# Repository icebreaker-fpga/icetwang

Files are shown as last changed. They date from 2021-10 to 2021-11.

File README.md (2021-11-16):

The iCEBreaker-Bitsy FPGA based 1D LED game system.

This repository contains hardware, gateware and firmware for the system.

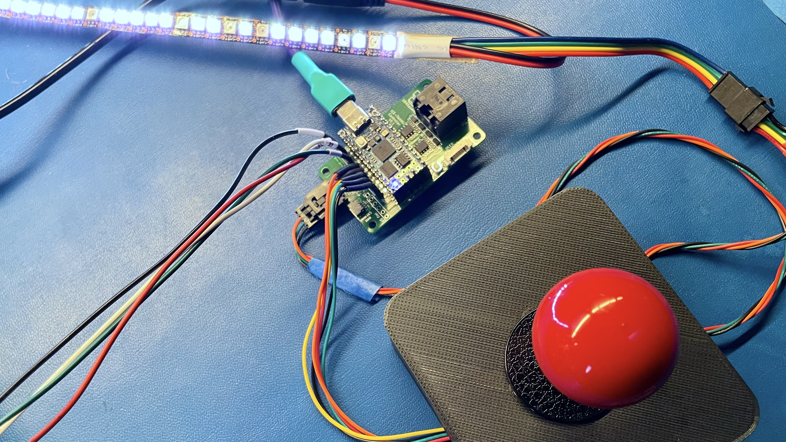
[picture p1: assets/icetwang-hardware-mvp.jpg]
The minimum vaiable setup, using the iCEtwang controller board, an APA102 LED strip and an arcade joystick

**The minimum vaiable setup, using the iCEtwang controller board, an APA102 LED strip and an arcade joystick**

# What is it

The original intention was to implement a [TWANG](https://www.buildlog.net/blog/2018/01/twang/)
inspired game, using FPGA instead of a microcontroller. In turn TWANG was inspired by the game
called [Line Wobbler](https://wobblylabs.com/projects/wobbler).

The scope of the project has expanded a bit since it's inception. The added
goals are multiplayer and remote LED strings, as well as additional games
beyond the 1D Dungeon game that the predecessor TWANG game implemented.

# Simulator

This repository also contains a simulator that allows you to play the game on
the desktop using keyboard arrow keys. It is very useful to try out the game
without the hardware, as well as debugging and development of the games.

iCEtwang simulator window
**The iCEtwang simulator window**

You can find it in the `sim` subdirectory.

## How to build the hardware

TODO: Hardware build information goes here...

## How to build the gateware

* Connect the iCEBitsy in DFU bootloader mode to your computer.
* In the `soc/ice-twang` directory run `make dfuprog`

## How to build the firmware

* Connect the iCEBitsy in DFU bootloader mode to your computer.
* In the `firmware/icetwang-controller` or `firmware/icetwang-pole` directory
  run `cargo run --release`

## More information

You should be able to find some more README.md files distributed around this
repository, describing more details of each of the system components.

If you have questions you can always join [our discord
server](https://1bitsquared.com/pages/chat) and ask questions there.

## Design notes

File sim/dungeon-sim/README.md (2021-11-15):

This is a desktop simulation of the iCEtwang-dungeon game.

This uses the game core from `../firmware/icetwang-dungeon` directory, and simulates the input using keyboard, and output using a graphical LED strip emulation.

To build the simulator just have rust installed and run:

```
cargo run
```

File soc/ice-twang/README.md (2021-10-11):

RISC-V core for 1D LED games (iCETWANG)
=========================================

For the iCEBreaker-bitsy, the hardware connections are :
  * `42`: USB DP
  * `38`: USB DN
  * `37`: Pull up. Resistor of 1.5 kOhm to USB DP 

To run :
  * Build and flash the bitstream
      * `make dfuprog`
      * This will build `fw/boot.hex` and include it as the BRAM initial data

  * You can flash the test c application code in SPI at offset 1M
      * `make -C fw dfuprog`
  
  * This project's main application can be found in `../../firmware/`
    directory. Follow the instructions there.

  * Connect to the iCEBreaker-bitsy uart console (P0, P1) with a 1M baudrate
      * and then at the `Command>` prompt, press `r` for 'run'. This will
        start the USB detection and device should enumerate

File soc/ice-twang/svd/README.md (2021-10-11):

The SVD file generator for icetwang-soc.

# How to generate the SVD file
The SVD file is generated using svdtools.

To install svdtools run:
```
pip3 innstall --upgrade --user svdtools
```

Or if you are on Arch you can install the svdtools AUR.

You can then run the `gensvd.sh` script. This will generate the svd file and
drop it into `../../../firmware/icetwang-pac`.

# How to add registers

Just edit the icetwang-soc.yaml file and add more registers.

For syntax refer to the [svdtools
documentation](https://pypi.org/project/svdtools/#device-and-peripheral-yaml-format).

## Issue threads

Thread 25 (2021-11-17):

Implement IMU driver

esden, 2021-11-17:
It depends on #24

esden, 2021-12-15:
It is now partly implemented. It can be tested in the blinky firmware. Still needs to be fully implemented in the main game firmware.

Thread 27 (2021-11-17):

Implement movable spring controller

esden, 2021-11-17:
The original spring controller has to be affixed to a solid surface. As we want to read out the bend of the spring and not the movement of the controller. We could solve the issue by adding a second IMU inside the controller itself and use its output as the reference frame to the IMU on the spring tip.

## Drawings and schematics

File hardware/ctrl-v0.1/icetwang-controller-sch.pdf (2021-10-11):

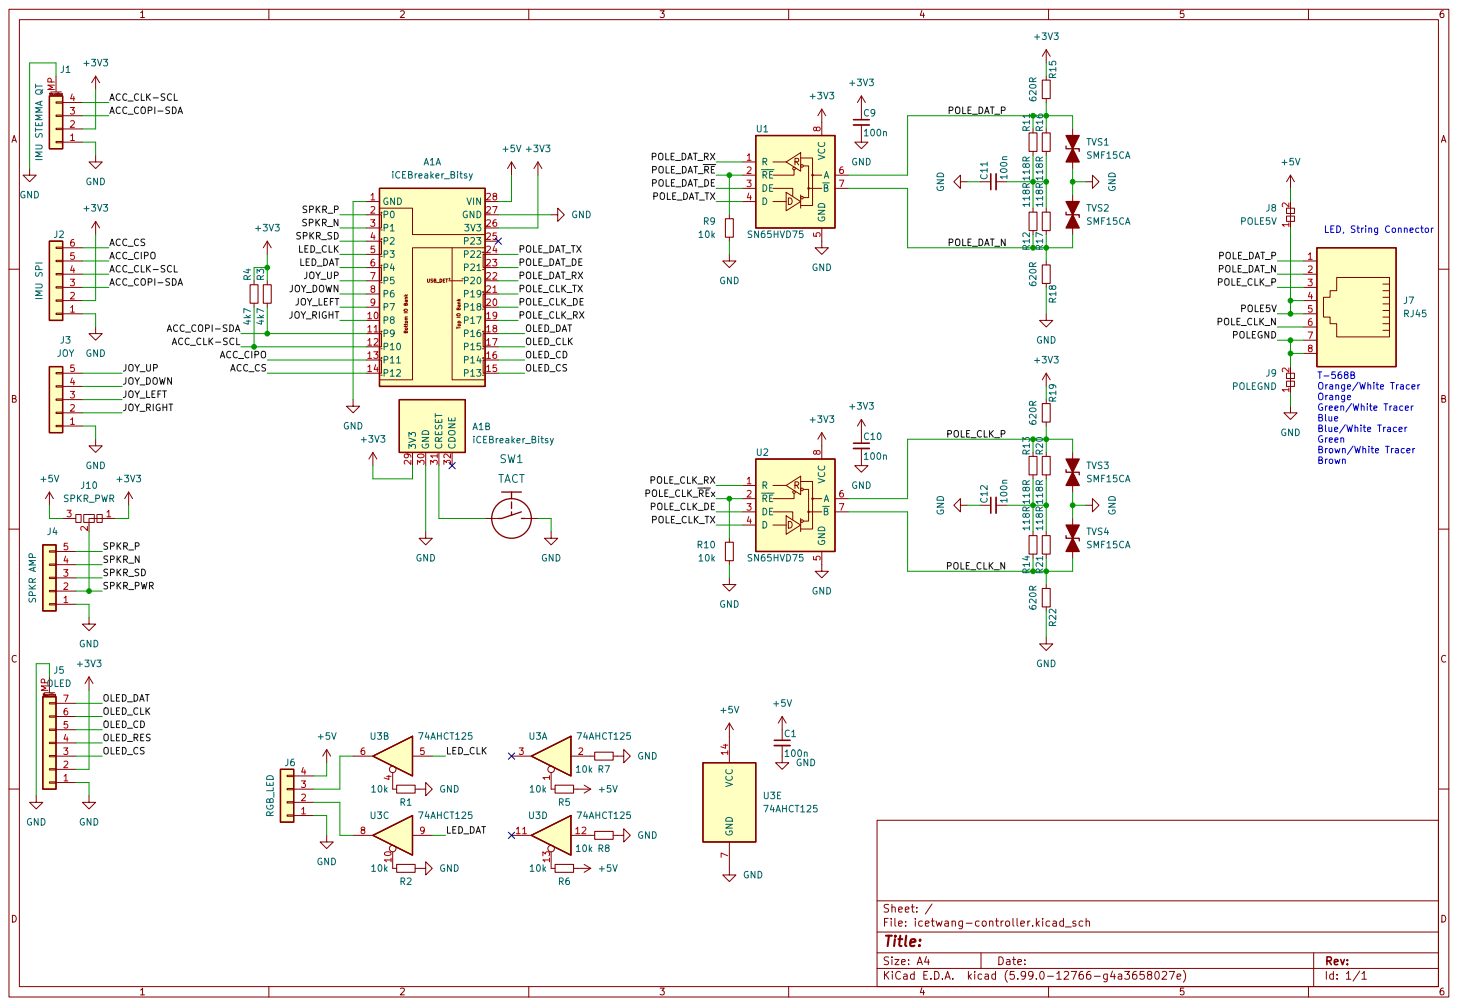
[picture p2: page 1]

LED, String Connector T-568B Orange/White Tracer

Orange Green/White Tracer Blue Blue/White Tracer Green Brown/White Tracer Brown

File: icetwang-controller.kicad_sch Sheet: / +5V
J6 RGB_LED

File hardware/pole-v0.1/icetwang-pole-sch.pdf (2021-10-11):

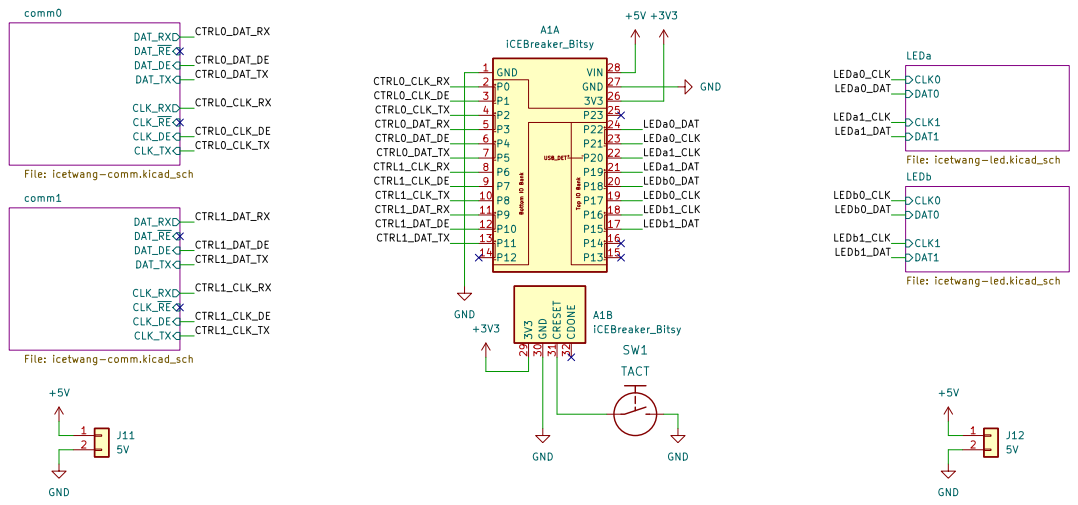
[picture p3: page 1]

LEDa File: icetwang-led.kicad_sch

License: CC-BY-SA 4.3 CLK_~{RE} CLK_RX CLK_DE CLK_TX DAT_DE DAT_~{RE} DAT_RX DAT_TX

(C) 2021 Piotr Esden-Tempski <piotr@esden.net>
(C) 2021 1BitSquared <info@1bitsquared.com>
File: icetwang-pole.kicad_sch Sheet: / 1BitSquared

Id: 1/5 Title: iCE-TWANG Pole

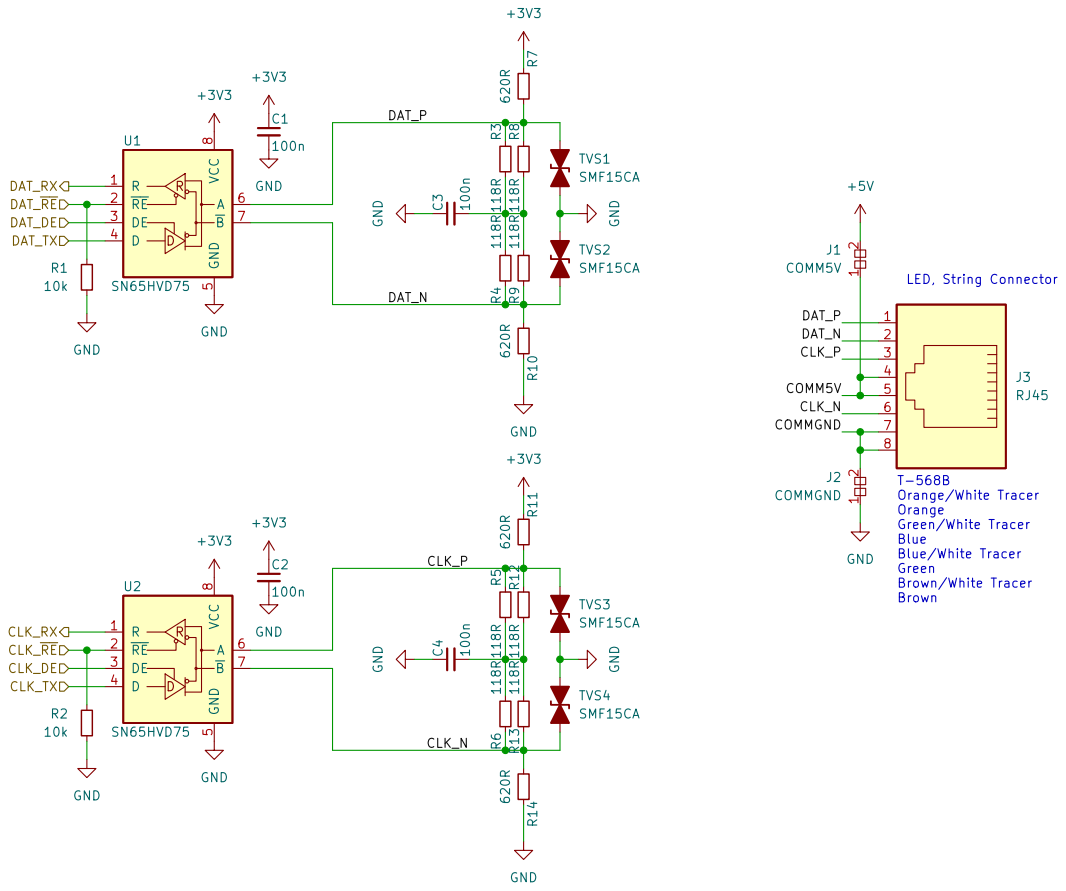
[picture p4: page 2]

+3V3R7 620R R3 118R GND
File: icetwang-comm.kicad_sch Sheet: /comm0/ 1 2

LED, String Connector T-568B Orange/White Tracer

Orange Green/White Tracer Blue Blue/White Tracer Green Brown/White Tracer Brown

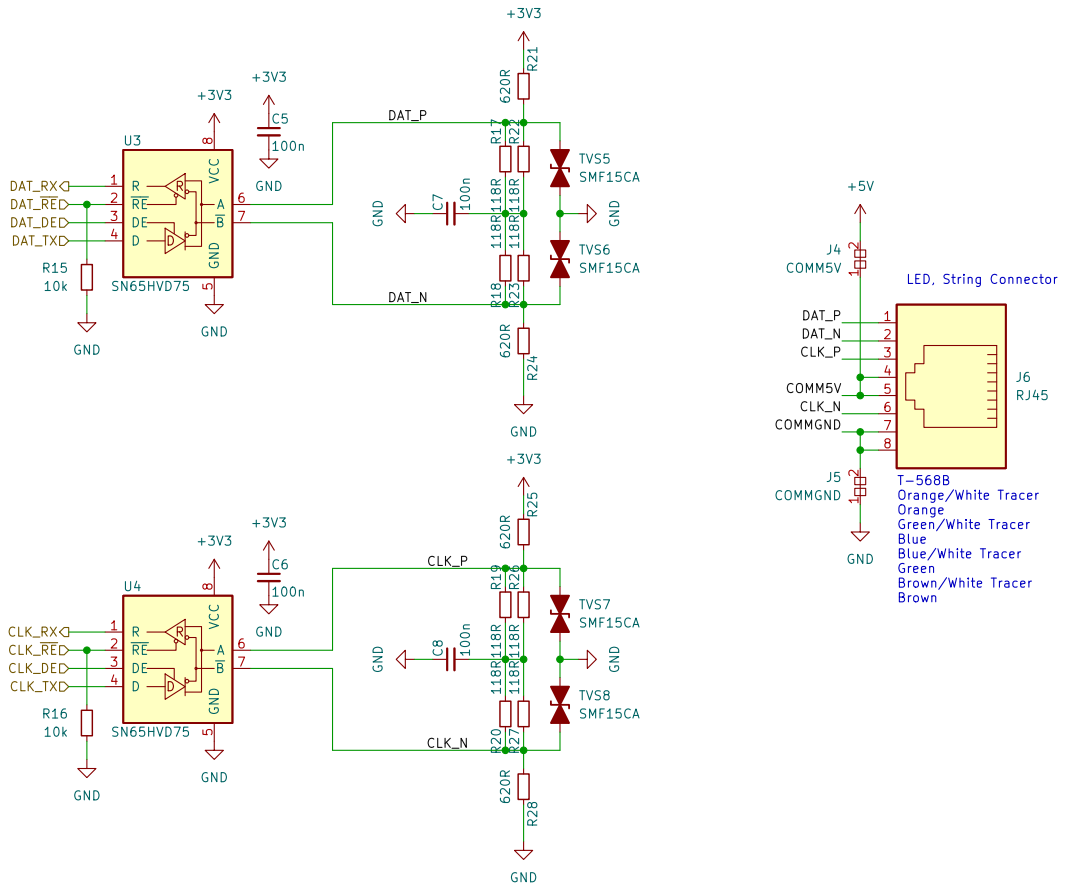
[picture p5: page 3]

+3V3R21 620R R17 118R GND
File: icetwang-comm.kicad_sch Sheet: /comm1/ 1 2

LED, String Connector T-568B Orange/White Tracer

Orange Green/White Tracer Blue Blue/White Tracer Green Brown/White Tracer Brown

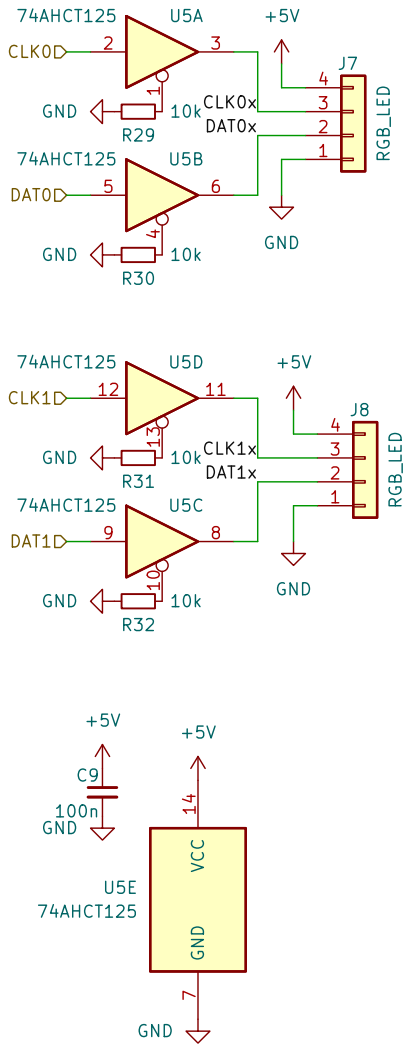
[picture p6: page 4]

File: icetwang-led.kicad_sch Sheet: /LEDa/ GND

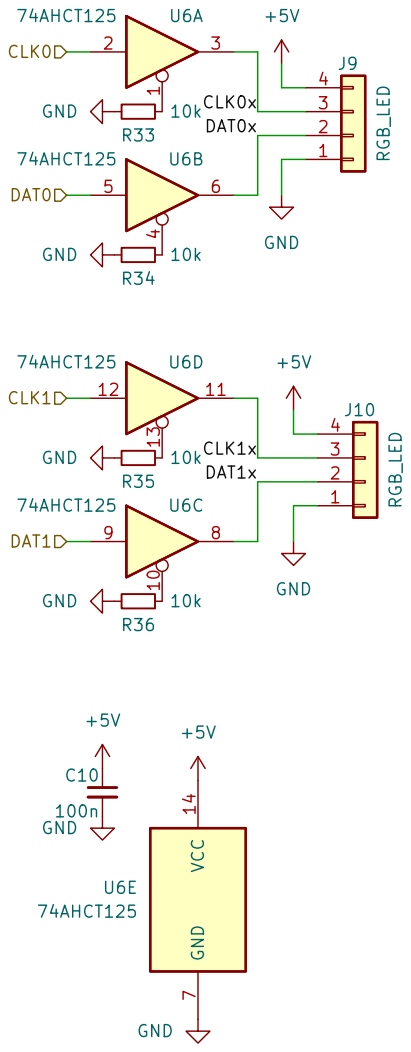
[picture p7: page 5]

File: icetwang-led.kicad_sch Sheet: /LEDb/ GND

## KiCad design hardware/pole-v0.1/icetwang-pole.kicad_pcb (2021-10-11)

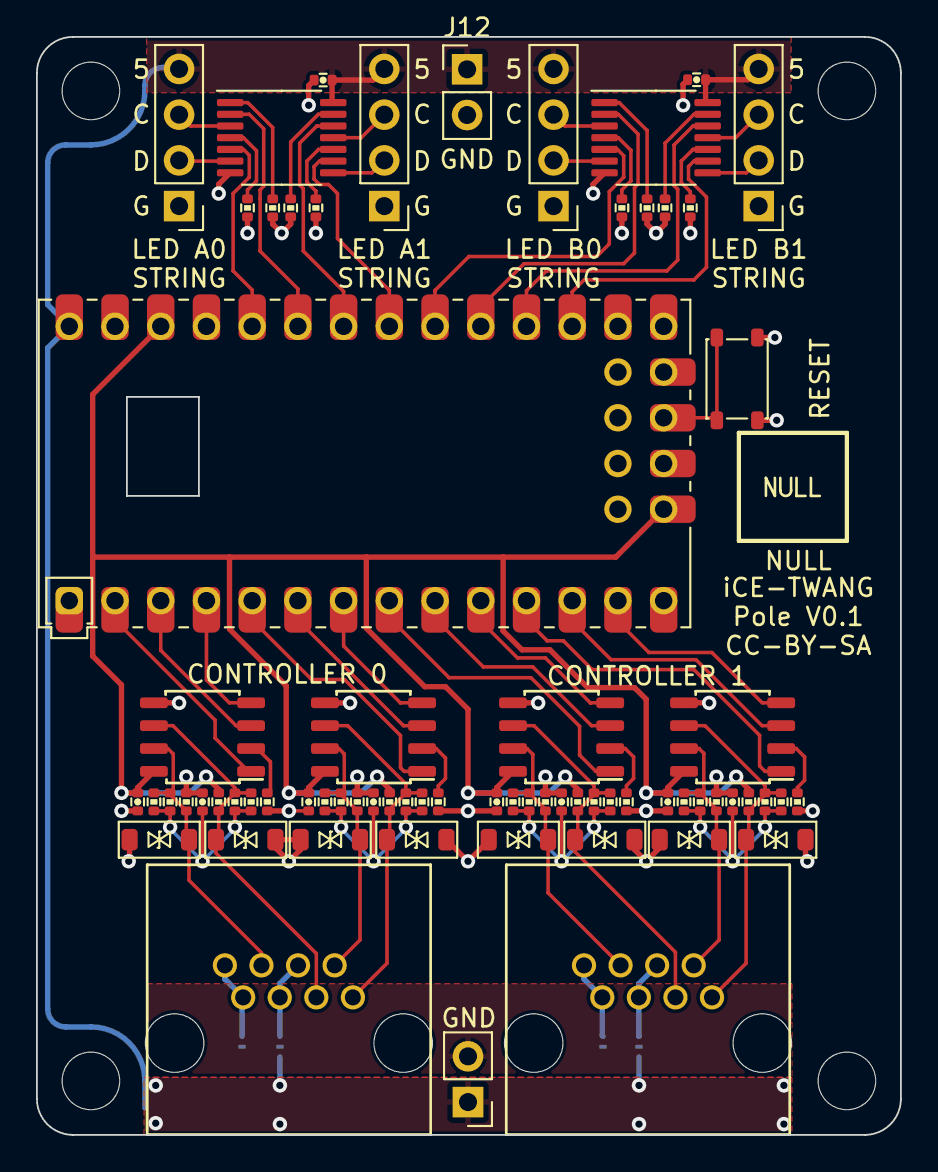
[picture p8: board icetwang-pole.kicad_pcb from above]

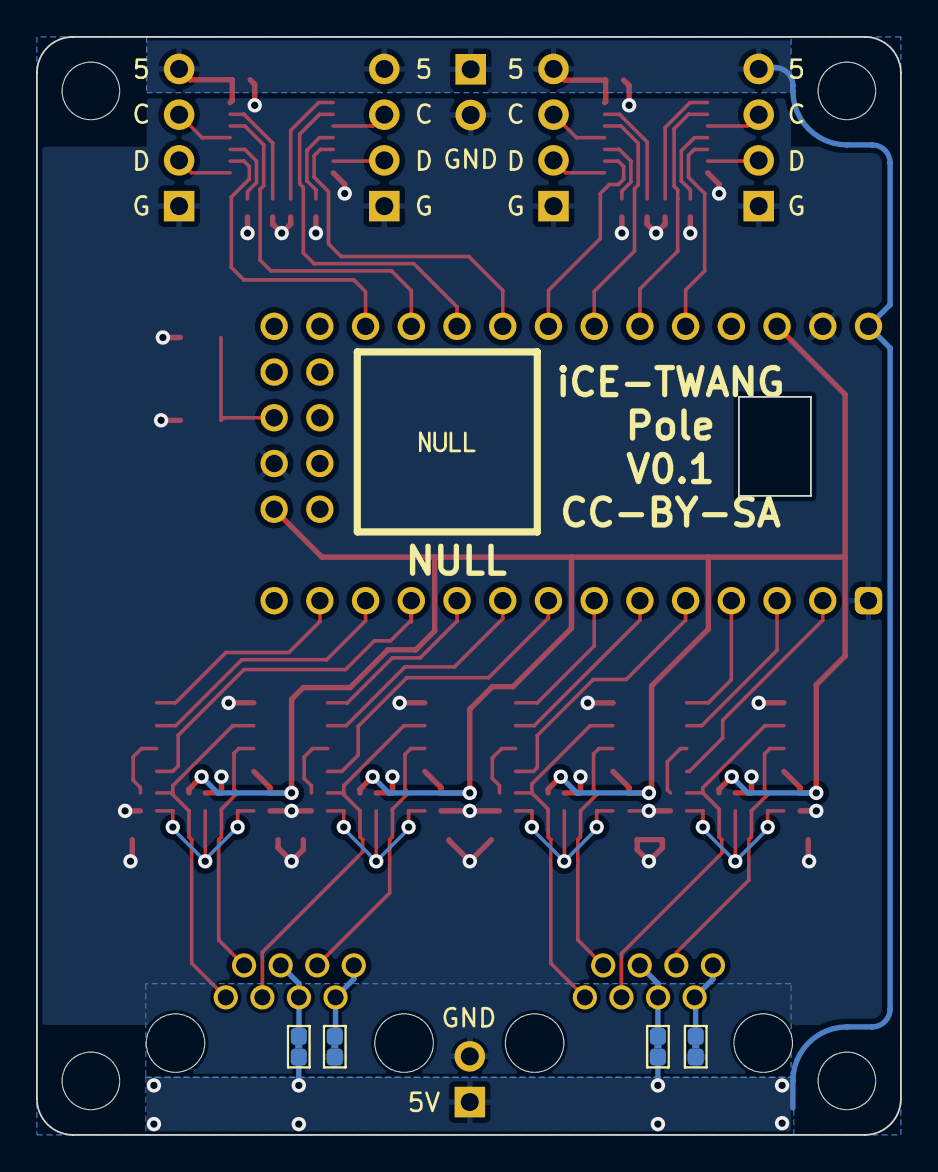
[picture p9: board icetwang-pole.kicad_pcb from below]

Board: 2 copper layers, 48.0 x 61.0 mm, 74 parts (4 on the bottom side), 60 nets.

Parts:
A1: iCEBreaker_Bitsy
C1, C2, C3, C4, C5, C6, C7, C8, C9, C10: 100n; C_0402
J1, J4: COMM5V; J_NC_0603_40
J2, J5: COMMGND; J_NC_0603_40
J3, J6: RJ45; AMPHENOL_RJHSE5080
J7, J8, J9, J10: RGB_LED; PinHeader_1x04_P2.54mm_Vertical
J11, J12: 5V; PinHeader_1x02_P2.54mm_Vertical
R1, R2, R15, R16, R29, R30, R31, R32, R33, R34, R35, R36: 10k; R_0402
R3, R4, R5, R6, R8, R9, R12, R13, R17, R18, R19, R20, R22, R23, R26, R27: 118R; R_0402
R7, R10, R11, R14, R21, R24, R25, R28: 620R; R_0402
SW1: TACT; SW_SPST_3x4x2.5
TVS1, TVS2, TVS3, TVS4, TVS5, TVS6, TVS7, TVS8: SMF15CA; D_SOD-123-TVS-BIDI
U1, U2, U3, U4: SN65HVD75; SOIC-8_5x4mm_Pitch1.27mm
U5, U6: 74AHCT125; TSSOP-14_4.4x5mm_P0.65mm

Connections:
+3V3: A1.26 (3V3), A1.29 (3V3), C1.1, C2.1, C5.1, C6.1, R7.1, R11.1, R21.1, R25.1, U1.8 (VCC), U2.8 (VCC), U3.8 (VCC), U4.8 (VCC)
+5V: A1.28 (VIN), C9.1, C10.1, J1.2, J4.2, J7.4, J8.4, J9.4, J10.4, J11.1, J12.1, U5.14 (VCC), U6.14 (VCC)
/CTRL0_CLK_DE: A1.3 (P1), U2.3 (DE)
/CTRL0_CLK_RX: A1.2 (P0), U2.1 (R)
/CTRL0_CLK_TX: A1.4 (P2), U2.4 (D)
/CTRL0_DAT_DE: A1.6 (P4), U1.3 (DE)
/CTRL0_DAT_RX: A1.5 (P3), U1.1 (R)
/CTRL0_DAT_TX: A1.7 (P5), U1.4 (D)
/CTRL1_CLK_DE: A1.9 (P7), U4.3 (DE)
/CTRL1_CLK_RX: A1.8 (P6), U4.1 (R)
/CTRL1_CLK_TX: A1.10 (P8), U4.4 (D)
/CTRL1_DAT_DE: A1.12 (P10), U3.3 (DE)
/CTRL1_DAT_RX: A1.11 (P9), U3.1 (R)
/CTRL1_DAT_TX: A1.13 (P11), U3.4 (D)
/LEDa0_CLK: A1.23 (P21), U5.2
/LEDa0_DAT: A1.24 (P22), U5.5
/LEDa1_CLK: A1.22 (P20), U5.12
/LEDa1_DAT: A1.21 (P19), U5.9
/LEDa/CLK0x: J7.3, U5.3
/LEDa/CLK1x: J8.3, U5.11
/LEDa/DAT0x: J7.2, U5.6
/LEDa/DAT1x: J8.2, U5.8
/LEDb0_CLK: A1.19 (P17), U6.2
/LEDb0_DAT: A1.20 (P18), U6.5
/LEDb1_CLK: A1.18 (P16), U6.12
/LEDb1_DAT: A1.17 (P15), U6.9
/LEDb/CLK0x: J9.3, U6.3
/LEDb/CLK1x: J10.3, U6.11
/LEDb/DAT0x: J9.2, U6.6
/LEDb/DAT1x: J10.2, U6.8
/comm0/CLK_N: J3.6, R6.1, R13.1, R14.1, TVS4.1 (A1), U2.7 (~B)
/comm0/CLK_P: J3.3, R5.1, R11.2, R12.1, TVS3.2 (A2), U2.6 (A)
/comm0/CLK_~RE: R2.1, U2.2 (~RE)
/comm0/COMM5V: J1.1, J3.4, J3.5
/comm0/COMMGND: J2.2, J3.7, J3.8
/comm0/DAT_N: J3.2, R4.1, R9.1, R10.1, TVS2.1 (A1), U1.7 (~B)
/comm0/DAT_P: J3.1, R3.1, R7.2, R8.1, TVS1.2 (A2), U1.6 (A)
/comm0/DAT_~RE: R1.1, U1.2 (~RE)
/comm1/CLK_N: J6.6, R20.1, R27.1, R28.1, TVS8.1 (A1), U4.7 (~B)
/comm1/CLK_P: J6.3, R19.1, R25.2, R26.1, TVS7.2 (A2), U4.6 (A)
/comm1/CLK_~RE: R16.1, U4.2 (~RE)
/comm1/COMM5V: J4.1, J6.4, J6.5
/comm1/COMMGND: J5.2, J6.7, J6.8
/comm1/DAT_N: J6.2, R18.1, R23.1, R24.1, TVS6.1 (A1), U3.7 (~B)
/comm1/DAT_P: J6.1, R17.1, R21.2, R22.1, TVS5.2 (A2), U3.6 (A)
/comm1/DAT_~RE: R15.1, U3.2 (~RE)
GND: A1.1 (GND), A1.27 (GND), A1.30 (GND), C1.2, C2.2, C3.1, C4.1, C5.2, C6.2, C7.1, C8.1, C9.2, C10.2, J2.1, J5.1, J7.1, J8.1, J9.1, J10.1, J11.2, J12.2, R1.2, R2.2, R10.2, R14.2, R15.2, R16.2, R24.2, R28.2, R29.2, R30.2, R31.2, R32.2, R33.2, R34.2, R35.2, R36.2, SW1.2, TVS1.1 (A1), TVS2.2 (A2), TVS3.1 (A1), TVS4.2 (A2), TVS5.1 (A1), TVS6.2 (A2), TVS7.1 (A1), TVS8.2 (A2), U1.5 (GND), U2.5 (GND), U3.5 (GND), U4.5 (GND), U5.7 (GND), U6.7 (GND)
unnamed: A1.31 (CRESET), SW1.1
unnamed: C3.2, R3.2, R4.2, R8.2, R9.2
unnamed: C4.2, R5.2, R6.2, R12.2, R13.2
unnamed: C7.2, R17.2, R18.2, R22.2, R23.2
unnamed: C8.2, R19.2, R20.2, R26.2, R27.2
unnamed: R29.1, U5.1
unnamed: R30.1, U5.4
unnamed: R31.1, U5.13
unnamed: R32.1, U5.10
unnamed: R33.1, U6.1
unnamed: R34.1, U6.4
unnamed: R35.1, U6.13
unnamed: R36.1, U6.10

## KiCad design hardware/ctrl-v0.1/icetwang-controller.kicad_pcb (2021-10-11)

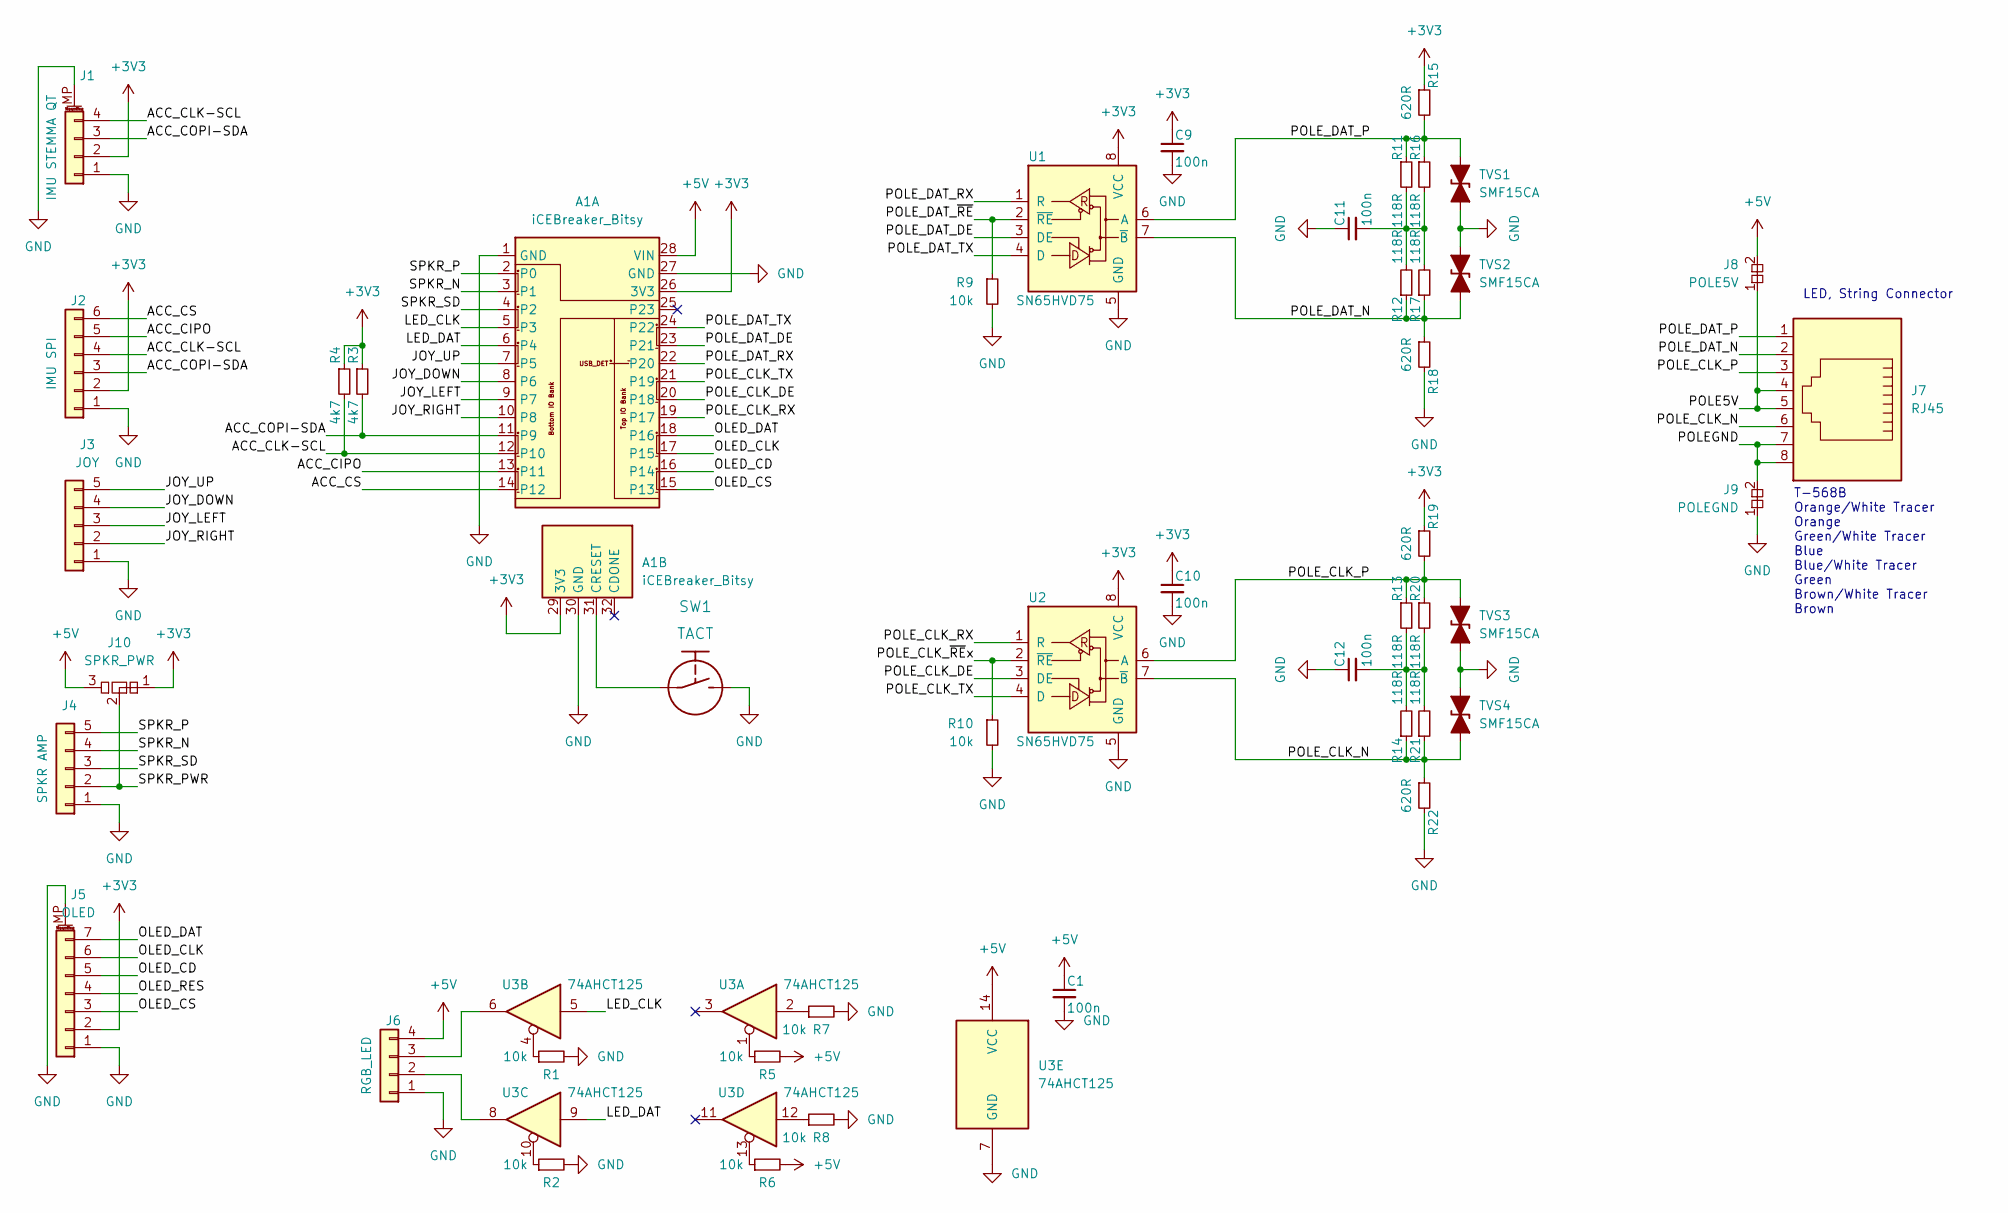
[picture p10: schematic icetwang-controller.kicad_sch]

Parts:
A1: iCEBreaker_Bitsy
C1, C9, C10, C11, C12: 100n; C_0402
J1: IMU STEMMA QT; JST_SH_SM04B-SRSS-TB_1x04-1MP_P1.00mm_Horizontal
J2: IMU SPI; PinHeader_1x06_P2.54mm_Vertical
J3: JOY; PinHeader_1x05_P2.54mm_Vertical
J4: SPKR AMP; PinHeader_1x05_P2.54mm_Vertical
J5: OLED; Molex_PicoBlade_53261-0771_1x07-1MP_P1.25mm_Horizontal
J6: RGB_LED; PinHeader_1x04_P2.54mm_Vertical
J7: RJ45; AMPHENOL_RJHSE5080
J8: POLE5V; J_NC_0603_40
J9: POLEGND; J_NC_0603_40
J10: SPKR_PWR; J_NCNO_0903_30
R1, R2, R5, R6, R7, R8, R9, R10: 10k; R_0402
R3, R4: 4k7; R_0402
R11, R12, R13, R14, R16, R17, R20, R21: 118R; R_0402
R15, R18, R19, R22: 620R; R_0402
SW1: TACT; SW_SPST_3x4x2.5
TVS1, TVS2, TVS3, TVS4: SMF15CA; D_SOD-123-TVS-BIDI
U1, U2: SN65HVD75; SOIC-8_5x4mm_Pitch1.27mm
U3: 74AHCT125; TSSOP-14_4.4x5mm_P0.65mm

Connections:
+3V3: A1.26 (3V3), A1.29 (3V3), C9.1, C10.1, J1.2, J2.2, J5.2, J10.1, R3.1, R4.1, R15.1, R19.1, U1.8 (VCC), U2.8 (VCC)
+5V: A1.28 (VIN), C1.1, J6.4, J8.2, J10.3, R5.2, R6.2, U3.14 (VCC)
/ACC_CIPO: A1.13 (P11), J2.5
/ACC_CLK-SCL: A1.12 (P10), J1.4, J2.4, R4.2
/ACC_COPI-SDA: A1.11 (P9), J1.3, J2.3, R3.2
/ACC_CS: A1.14 (P12), J2.6
/JOY_DOWN: A1.8 (P6), J3.4
/JOY_LEFT: A1.9 (P7), J3.3
/JOY_RIGHT: A1.10 (P8), J3.2
/JOY_UP: A1.7 (P5), J3.5
/LED_CLK: A1.5 (P3), U3.5
/LED_DAT: A1.6 (P4), U3.9
/OLED_CD: A1.16 (P14), J5.5
/OLED_CLK: A1.17 (P15), J5.6
/OLED_CS: A1.15 (P13), J5.3
/OLED_DAT: A1.18 (P16), J5.7
/OLED_RES: J5.4
/POLE5V: J7.4, J7.5, J8.1
/POLEGND: J7.7, J7.8, J9.2
/POLE_CLK_DE: A1.20 (P18), U2.3 (DE)
/POLE_CLK_N: J7.6, R14.1, R21.1, R22.1, TVS4.1 (A1), U2.7 (~B)
/POLE_CLK_P: J7.3, R13.1, R19.2, R20.1, TVS3.2 (A2), U2.6 (A)
/POLE_CLK_RX: A1.19 (P17), U2.1 (R)
/POLE_CLK_TX: A1.21 (P19), U2.4 (D)
/POLE_CLK_~REx: R10.1, U2.2 (~RE)
/POLE_DAT_DE: A1.23 (P21), U1.3 (DE)
/POLE_DAT_N: J7.2, R12.1, R17.1, R18.1, TVS2.1 (A1), U1.7 (~B)
/POLE_DAT_P: J7.1, R11.1, R15.2, R16.1, TVS1.2 (A2), U1.6 (A)
/POLE_DAT_RX: A1.22 (P20), U1.1 (R)
/POLE_DAT_TX: A1.24 (P22), U1.4 (D)
/POLE_DAT_~RE: R9.1, U1.2 (~RE)
/SPKR_N: A1.3 (P1), J4.4
/SPKR_P: A1.2 (P0), J4.5
/SPKR_PWR: J4.2, J10.2
/SPKR_SD: A1.4 (P2), J4.3
GND: A1.1 (GND), A1.27 (GND), A1.30 (GND), C1.2, C9.2, C10.2, C11.1, C12.1, J1.1, J1.MP (MountPin), J2.1, J3.1, J4.1, J5.1, J5.MP (MountPin), J6.1, J9.1, R1.2, R2.2, R7.2, R8.2, R9.2, R10.2, R18.2, R22.2, SW1.2, TVS1.1 (A1), TVS2.2 (A2), TVS3.1 (A1), TVS4.2 (A2), U1.5 (GND), U2.5 (GND), U3.7 (GND)
unnamed: A1.31 (CRESET), SW1.1
unnamed: C11.2, R11.2, R12.2, R16.2, R17.2
unnamed: C12.2, R13.2, R14.2, R20.2, R21.2
unnamed: R1.1, U3.4
unnamed: R2.1, U3.10
unnamed: R5.1, U3.1
unnamed: R6.1, U3.13
unnamed: R7.1, U3.2
unnamed: R8.1, U3.12
unnamed: J6.3, U3.6
unnamed: J6.2, U3.8

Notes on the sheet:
T-568B Orange/White Tracer Orange Green/White Tracer Blue Blue/White Tracer Green Brown/White Tracer Brown
LED, String Connector

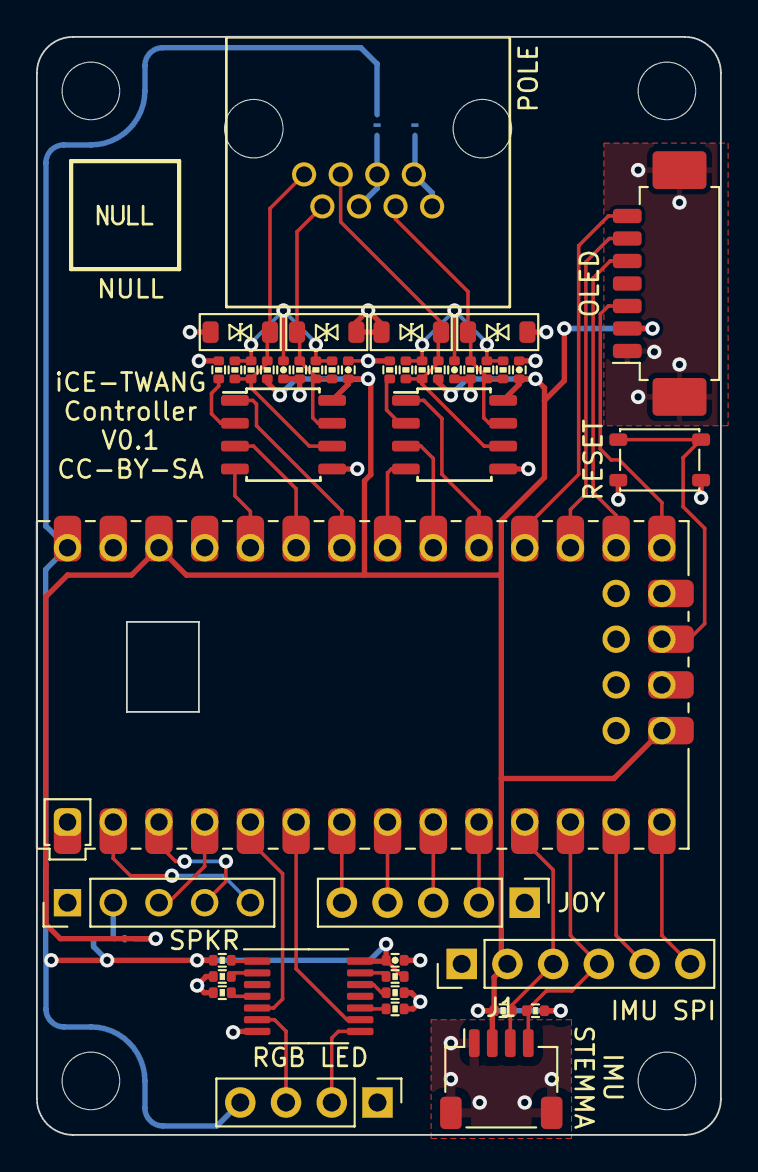
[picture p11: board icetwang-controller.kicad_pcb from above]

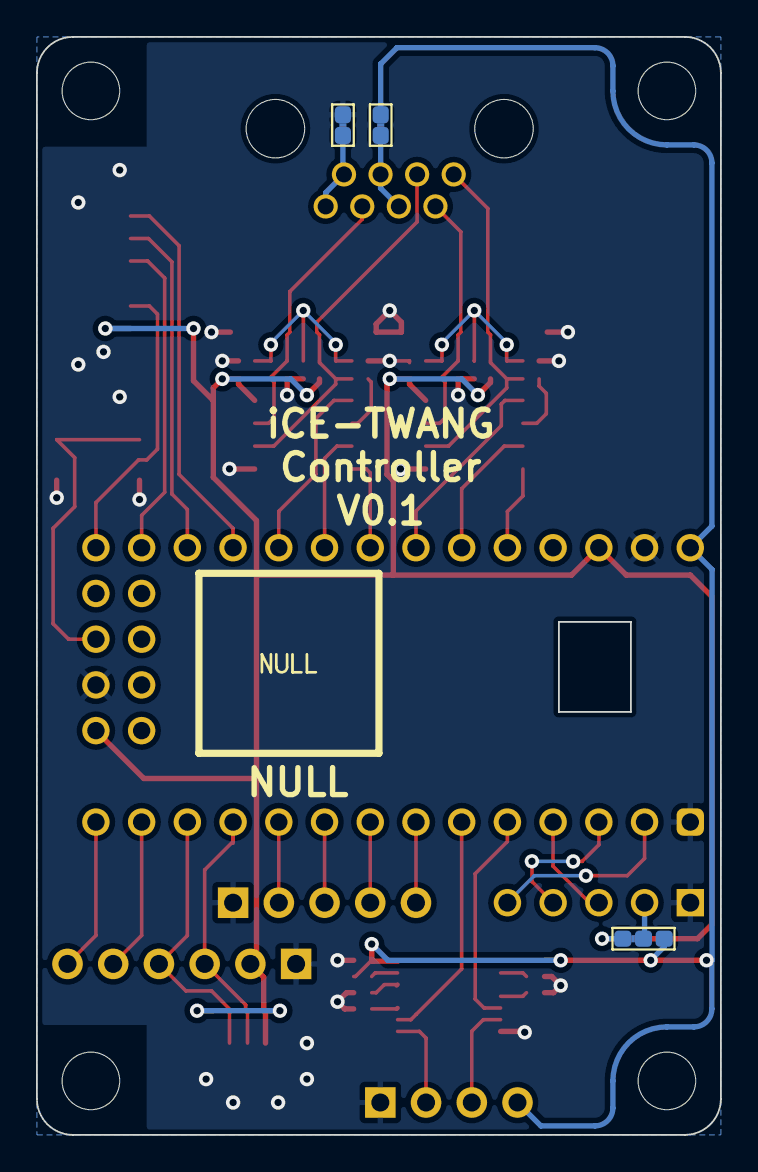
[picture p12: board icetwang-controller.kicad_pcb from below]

Board: 2 copper layers, 38.0 x 61.0 mm, 46 parts (3 on the bottom side), 46 nets.

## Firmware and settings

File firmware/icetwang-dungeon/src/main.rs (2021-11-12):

/*
 * Copyright (c) 2021, Piotr Esden-Tempski <piotr@esden.net>
 *
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
 * THIS SOFTWARE IS PROVIDED BY THE COPYRIGHT HOLDERS AND CONTRIBUTORS "AS IS" AND
 * ANY EXPRESS OR IMPLIED WARRANTIES, INCLUDING, BUT NOT LIMITED TO, THE IMPLIED
 * WARRANTIES OF MERCHANTABILITY AND FITNESS FOR A PARTICULAR PURPOSE ARE
 * DISCLAIMED. IN NO EVENT SHALL THE COPYRIGHT OWNER OR CONTRIBUTORS BE LIABLE FOR
 * ANY DIRECT, INDIRECT, INCIDENTAL, SPECIAL, EXEMPLARY, OR CONSEQUENTIAL DAMAGES
 * (INCLUDING, BUT NOT LIMITED TO, PROCUREMENT OF SUBSTITUTE GOODS OR SERVICES;
 * LOSS OF USE, DATA, OR PROFITS; OR BUSINESS INTERRUPTION) HOWEVER CAUSED AND
 * ON ANY THEORY OF LIABILITY, WHETHER IN CONTRACT, STRICT LIABILITY, OR TORT
 * (INCLUDING NEGLIGENCE OR OTHERWISE) ARISING IN ANY WAY OUT OF THE USE OF THIS
 * SOFTWARE, EVEN IF ADVISED OF THE POSSIBILITY OF SUCH DAMAGE.
 */

#![no_std]
#![no_main]

// Hardware crates
//extern crate panic_halt;

use core::panic::PanicInfo;
use core::sync::atomic::{self, Ordering};

use icetwang_pac;
use ledstr_hal::LEDStringHAL;
use riscv_rt::entry;

mod timer;
mod rgbled;
mod print;
mod ledstr_hal;
mod joy;

use timer::Timer;
use rgbled::RGBLed;
use joy::Joy;

// Game crates
mod twang;

/* 4m long 60 LED/m strip */
//const LED_STRING_LENGTH: usize = 4 * 60;
//const LED_GLOBAL_BRIGHTNESS: u16 = 0x1F; /* for outdoor use */

/* 1m long 144 LED/m strip */
const LED_STRING_LENGTH: usize = 144;
const LED_GLOBAL_BRIGHTNESS: u16 = 2; /* for indoor use */

// This is the entry point for the application.
// It is not allowed to return.

fn real_main() -> ! {

    // Initialize hardware
    // -------------------
    let peripherals = icetwang_pac::Peripherals::take().unwrap();

    // Configure uart for the print macro
    print::print_hardware::set_hardware(peripherals.UART);
    print::print_hardware::set_divider(22); // Set baud to 1MBaud

    // Configure the timer
    let mut timer = Timer::new(peripherals.TIMER);
    let event_time = 16000;
    timer.load(event_time); // We want the timer ev to trigger every 1/60th of a second
    timer.reload(event_time);
    timer.enable_ev();

    // Configure the RGBLed
    let mut rgbled = RGBLed::new(peripherals.RGBLED);
    rgbled.color(96, 10, 5);
    rgbled.blink(true, 200, 1000);
    rgbled.breathe(true, 100, 200);
    rgbled.state(true);

    // Configure the LED String
    let mut ledstring_hal = LEDStringHAL::new(peripherals.LEDSTR);

    ledstring_hal.set_len(LED_STRING_LENGTH as u16 - 1); // The HAL min length is 1 represented by 0
    ledstring_hal.set_div(0);
    ledstring_hal.set_glob(LED_GLOBAL_BRIGHTNESS);
    for i  in 0..LED_STRING_LENGTH as u16 {
        ledstring_hal.write_rgb(i, [i as u8, 0x00, 0x00]);
    }
    // Output the inital LED string state
    ledstring_hal.start();

    // Configure the Joystick
    let mut joy = Joy::new(peripherals.JOY);

    // Initialize Game
    // ---------------
    let mut twang = twang::Twang::new();
    let mut lr_input: i32;
    let mut fire_input: bool;
    let mut time: u32 = 0;

    // Print debug header
    println!("\nDir  CPU  us");

    // Start timer
    timer.enable();

    // Main system loop
    loop {
        // Get joystick input
        let joystate = joy.get();
        print!("{}{}{}{}",
            if joystate.left {"<"} else {" "},
            if joystate.right {">"} else {" "},
            if joystate.up {"^"} else {" "},
            if joystate.down {"v"} else {" "});

        // Cycle game logic
        lr_input = 0;
        if joystate.left {
            lr_input = -10;
        }
        if joystate.right {
            lr_input =  10;
        }
        fire_input = joystate.up || joystate.down;

        twang.cycle(lr_input, fire_input, time);

        // Make sure the LED string is ready for us
        let mut bsy = false;
        while ledstring_hal.bsy_n() {
            print!("b");
            bsy = true;
        }
        if bsy {
            println!(""); // Add a newline if we printed some delay indicators
        }

        // Send the LED values to the hardware
        let len = twang.get_led_len();
        for i in 0..len {
            let led = twang.get_led(i as usize);
            ledstring_hal.write_rgb((len - 1 - i) as u16, led);
        }
        ledstring_hal.start();

        // Calculate elapsed and percentage of the frame time
        let time_elapsed = event_time - timer.value();
        let busy_percent = (time_elapsed * 100) / event_time;
        print!(" {:03}% {:5} {:10}\x1b[0K\r", busy_percent, time_elapsed, time);

        // Wait for the timer to expire
        while !timer.ev_n() {
            //println!("tmr: {:#010X} {:#06b}", timer.value(), (timer.csr() & 0xFF) as u8);
        }
        timer.ev_rst(); // Reset event

        // Advance time (we track time in msec but the timer runs in usec)
        time = time.wrapping_add(event_time/1000);
    }
}

#[entry]
fn main() -> ! {
    real_main();
}

#[inline(never)]
#[panic_handler]
fn panic(info: &PanicInfo) -> ! {
    println!("\r\n==> {}", info);
    loop {
        atomic::compiler_fence(Ordering::SeqCst);
    }
}

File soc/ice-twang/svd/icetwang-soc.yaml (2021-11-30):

# Path to the SVD template file
_svd: svdtemplate.svd

# Include other YAML files if needed.
# Path is relative to this file location.
#_include:
#  - "xyz.yaml"

_modify:
  vendor: 1BitSquared
  name: iCETwang-SOC
  version: 0.1
  description: iCETwang 1D Dungeon SOC
  addressUnitBits: 8
  width: 32
  access: read-write
  size: 0x20
  resetValue: 0x0
  resetMask: 0xFFFFFFFF

# Start adding peripherals
# UART     0x81000000
# SPI      0x82000000
# LED      0x83000000
# USB_CORE 0x84000000
# USB_DATA 0x85000000
# KEYSCAN  0x86000000 (icekeeb)
_add:
  UART:
    description: UART interface
    groupName: UART
    baseAddress: 0x81000000
    addressBlock:
      offset: 0x0
      size:   0x01000000
      usage: registers
    registers:
      DATA:
        description: UART data in/out register. HSB 0 indicates pending data.
        addressOffset: 0x0
        access: read-write
        resetValue: 0x00000000
        fields:
          DATABYTE:
            description: The actual data input and output.
            bitOffset: 0
            bitWidth: 8
          RFEMPTY:
            description: Receive FIFO empty flag
            bitOffset: 31
            bitWidth: 1
      CSR:
        description: UART Config and Status Register
        addressOffset: 0x4
        access: read-write
        resetValue: 0x00000000
        fields:
          DIV:
            description: Baud rate clock divider
            bitOffset: 0
            bitWidth: 12
          TFFULL:
            description: Transmit FIFO full flag
            bitOffset: 28
            bitWidth: 1
          TFEMPTY:
            description: Transmit FIFO empty flag
            bitOffset: 29
            bitWidth: 1
          RFOVERFLOW:
            description: Receive FIFO overflow flag
            bitOffset: 30
            bitWidth: 1
          RFEMPTY:
            description: Receive FIFO empty flag
            bitOffset: 31
            bitWidth: 1
  RGBLED:
    description: RGBLED control
    groupName: RGBLED
    baseAddress: 0x83000000
    addressBlock:
      offset: 0x0
      size:   0x01000000
      usage: registers
    registers:
      CSR:
        description: Control and Status Register
        addressOffset: 0x0
        access: read-write
        resetValue: 0x00000000
        fields:
          LEDDEXE:
            description: Enable the IP to run the blinking sequence. When low, the sequence stops at the nearest OFF state
            bitOffset: 1
            bitWidth: 1
          RGBLEDEN:
            description: Enable control of the RGB LED
            bitOffset: 2
            bitWidth: 1
          CURREN:
            description: Power up
            bitOffset: 3
            bitWidth: 1
      PWRR:
        description: Pulse Width Register Red
        addressOffset: 0x44
        access: read-write
        resetValue: 0x00000000
      PWRG:
        description: Pulse Width Register Green
        addressOffset: 0x48
        access: read-write
        resetValue: 0x00000000
      PWRB:
        description: Pulse Width Register Blue
        addressOffset: 0x4C
        access: read-write
        resetValue: 0x00000000
      BCRR:
        description: Breathe Control Rise Register
        addressOffset: 0x54
        access: read-write
        resetValue: 0x00000000
        fields:
          BRATE:
            description: Breathe ON Rate
            bitOffset: 0
            bitWidth: 4
          BMODE:
            description: Breathe Mode Select 0= Breathe with local rate, 1= Modulate rate based on color setting
            bitOffset: 5
            bitWidth: 1
          BEDGE:
            description: Breathe Edge 0= Breathe control only for ON ramp, 1= Breathe control for ON and OFF ramp
            bitOffset: 6
            bitWidth: 1
          BON:
            description: Breathe ON Enable
            bitOffset: 7
            bitWidth: 1
      BCFR:
        description: Breathe Control Fall Register
        addressOffset: 0x58
        access: read-write
        resetValue: 0x00000000
        fields:
          BRATE:
            description: Breathe OFF Rate
            bitOffset: 0
            bitWidth: 4
          BMODE:
            description: Breathe Mode Select 0= Breathe with local rate, 1= Modulate rate based on color setting
            bitOffset: 5
            bitWidth: 1
          BRANGE:
            description: Breathe Range extend for linear mode
            bitOffset: 6
            bitWidth: 1
          BON:
            description: Breathe OFF Enable
            bitOffset: 7
            bitWidth: 1
      CR0:
        description: Control Register 0
        addressOffset: 0x60
        access: read-write
        resetValue: 0x00000000
        fields:
          BRMSBEXT:
            description: Pre-scale register MSB extension
            bitOffset: 0
            bitWidth: 2
          PWM_MODE:
            description: 0= Linear, 1= LFSR
            bitOffset: 2
            bitWidth: 1
          QUICK_STOP:
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

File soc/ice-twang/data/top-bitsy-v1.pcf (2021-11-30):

# SPI
set_io -nowarn spi_mosi 14
set_io -nowarn spi_miso 17
set_io -nowarn spi_clk 15
set_io -nowarn spi_flash_cs_n 16
set_io -nowarn spi_ram_cs_n 6

# USB
set_io -nowarn usb_dp 42
set_io -nowarn usb_dn 38
set_io -nowarn usb_pu 37

# UART
set_io -nowarn uart_rx 47
set_io -nowarn uart_tx 44

# Clock
set_io -nowarn clk_in 35

# Button
set_io -nowarn btn 2

# Leds
set_io -nowarn rgb[0] 39
set_io -nowarn rgb[1] 40
set_io -nowarn rgb[2] 41
set_io -nowarn led    25 # P13

# LED String
set_io -nowarn ls_clk  45
set_io -nowarn ls_data  4

# Arcade Joystick
set_io -nowarn joy_up    3  # P5
set_io -nowarn joy_down  9  # P6
set_io -nowarn joy_left  10 # P7
set_io -nowarn joy_right 11 # P8

# I2C
set_io -nowarn i2c_sda   12 # P9
set_io -nowarn i2c_scl   21 # P10

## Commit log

2021-10-05 Initial commit of the ctrl and pole PCB designs.
    [icetwang-comm.kicad_sch, icetwang-controller.kicad_pcb, icetwang-controller.kicad_sch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]
2021-10-11 Swapped to NULL logos and added pdf schematics.
    [icetwang-controller.kicad_pcb, icetwang-pole.kicad_pcb]
2021-10-17 Implemented print macro using UART.
2021-10-18 Minor module use fix.
    [main.rs]
2021-10-18 Initial commit of the lowest level APA102 LED protocol generator.
    This includes a testbench to excercise the generator.
2021-10-27 First draft of the ledstring wishbone interface with framebuffer.
2021-10-27 Initial test code to excercise the ledstring framebuffer interface.
2021-10-30 Initial LED string FB with Rust control.
2021-10-31 Added timer hardware. Fixed register offset issue in Rust.
    Now we are able to use a hardware timer to keep framerate.
    [icetwang-soc.yaml, main.rs, pac.rs]
2021-10-31 Fixed joystick decoding. Improved debug output.
    [main.rs]
2021-11-01 Renamed the hardware ledstring interface to hal.
    Also changed the led data format to be compatible with the rtwang code.
2021-11-02 Moved virtual led string inside twang.
    Also the virtual string is now 1000 LED long and mapped to the physical
    size.
2021-11-03 Added and updated missing license headers.
    [main.rs, mod.rs, print.rs]
2021-11-03 Added conveyors.
2021-11-11 Add a panic handler.
    The new panic handler prints the panic information to the serial debug
    console.
2021-11-11 Made the use of our embedded print optional.
    Preparing to add simulated version of the game.
2021-11-12 Modified drawing to use the raw LED data directly.
    This saves a lot of computation as one does not have to map from the
    virtual string to the real one with every pixel write. Also we only use
    as much CPU as we really need to. We still might run out of frame time
    when using really long LED strings, but not having to do the mapping
    calculation for every pixel will not happen on every LED so it will
    still be better.
2021-11-12 Added the FastLED random8 implementation.
    Replaced my even less good pseudo random algorithm in screensaver with
    the "new" one.
    [mod.rs]
2021-11-12 Made the enemies unaffected by the conveyor belts.
2021-11-12 Fixed enemy/player side calculation.
    Enemies that spawend behind the player had the wrong side set.
    Also fixed level 8, the spawner was sending the enemies in the wrong
    direction.
    [mod.rs]
2021-11-13 Added first half of the death animation.
    Still missing the particles.
    [mod.rs]
2021-11-13 Added player lives, display and reset to begining when out of lives.
    [mod.rs]
2021-11-18 Removed state stage repetition in loopback state transitions.
2021-11-30 Initial commit and test of i2c peripheral and IMU read.
2021-12-01 Ported i2c driver to use embedded-hal.
2021-12-08 Make timer not run when en is not set.
2021-12-08 Added timer testbench
2021-12-08 Added blocking delay traits to timer.
2021-12-08 Fixed timer bug. `prev_en` was not resetting when disabling the timer.
2021-12-08 Cleaned up. Now reading out the IMU works using the sensor crate.

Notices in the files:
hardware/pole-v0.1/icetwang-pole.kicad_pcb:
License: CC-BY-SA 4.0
